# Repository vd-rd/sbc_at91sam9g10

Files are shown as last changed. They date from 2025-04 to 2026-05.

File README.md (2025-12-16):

# Glasnost M9G10 - Open Hardware Linux SBC

An open hardware and software Single Board Computer based on the Microchip AT91SAM9G10, designed for IoT and embedded applications with full SPI/UART/I2C expansion capabilities. This is a learning project exploring Linux board design with mainline kernel support.

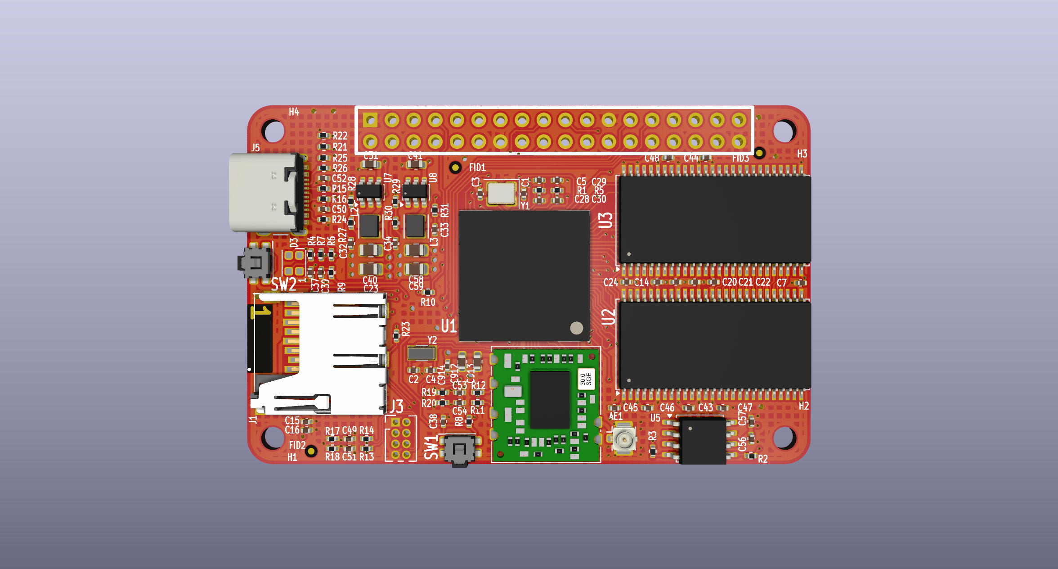
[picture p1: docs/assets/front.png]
board_render


### Features

| Characteristic | Description |
| --- | --- |
| Dimensions | 66mm x 42mm |
| Processor | AT91SAM9G10 - ARM926EJ @ 266MHz |
| Oscillators |  18.432MHz main clock, 32.768kHz RTC |
| RAM | SDRAM 1Gb max (2x 512Mbit modules) |
| Storage | microSD |
| USB | 1 microUSB Host/Client, 2 USB host |
| Ethernet | N/A |
| WiFi/BT | WiFi module onboard |
| Supply | USB, 5V max |
| Interfaces | SPI, UART, I2C, GPIO exposed on headers |
| OS Support | Linux (mainline kernel with custom device tree) |

Common interfaces such as I2C, SPI, UART and GPIO are exposed on the header.

### ⚠️ Boot Note

> **Unlike other Glasnost boards**, this SBC does **not** include NOR Flash for a recovery environment. The AT91SAM9G10's limited peripheral availability means the board relies entirely on microSD card boot. Linux must be booted from the microSD card—there is no fallback recovery distro on internal flash.

### Tools & Design

This project is created using **KiCad 9**

### Documentation & Resources

Complete documentation including schematics, PCB design, and build instructions is available in the [docs](docs/) directory and published at the project website.

For pre-built artifacts:
   - [Fabrication files and releases](https://github.com/vd-rd/sbc_at91sam9g10/releases)

### Status & Licensing

- **Status**: Stable
- **License**: Open Hardware (not officially certified, community design)
- **Open Source**: All hardware designs and software are open source

### References & Inspiration

- [AT91SAM9G10 Datasheet](resources/Atmel-6062-ARM926EJ-S-Microprocessor-SAM9261_Datasheet.pdf)
- [AT91SAM9G10EK Evaluation Kit](https://www.microchip.com/)
- [AT91Bootstrap](https://github.com/linux4sam/at91bootstrap)

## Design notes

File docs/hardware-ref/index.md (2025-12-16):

# Hardware Documentation

This section provides everything you need to understand, replicate, and work with the Glasnost M9G10 board. Whether you're just getting familiar with the design or planning to build your own, the following pages will guide you through each stage.

## 📘 Sections

- [Introduction](introduction.md): An overview of the board’s purpose, key features, and target use cases.
- [Schematics](schematics.md): Detailed circuit diagrams explaining the hardware design.
- [PCB](pcb.md): Information about the board layout, layer stackup, and routing considerations.
- [BOM](bom.md): A full bill of materials with part numbers and sourcing recommendations.
- [Build your own](build-your-own.md): Instructions and files to help you manufacture or assemble your own board.

---

Feel free to explore each section based on your needs, from design deep-dives to practical build guidance.

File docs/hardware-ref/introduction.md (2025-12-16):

# Introduction

The Glasnost M9G10 is an open hardware IoT platform based on the Microchip AT91SAM9G10 SoC. It is designed for projects that require connectivity, reliability, and full control over both software and hardware. The board runs Linux and is intended for embedded applications where flexibility and openness are essential.

## Key Features

- ARM926EJ-S processor @ 266 MHz
- Up to 128 MB low-power SDRAM
- NOR flash for boot and storage
- USB host/device support
- Multiple UARTs, SPI, I²C, GPIO
- Ethernet and other connectivity options
- Fully open hardware design with replicable manufacturing files

## About This Documentation

This section provides the technical resources and guidance needed to understand, replicate, and work with the hardware:
- Schematics and electrical design files
- PCB layout and mechanical notes
- Bill of materials with part numbers
- Assembly guidance and sourcing suggestions

## Intended Audience

This board is intended for:
- Developers building custom IoT hardware
- Researchers designing and testing embedded systems
- Hobbyists and hackers

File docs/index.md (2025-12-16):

---
template: home.html
title: GLASNOST M9G10
---

# Glasnost M9G10

An open hardware and software Single Board Computer based on the Microchip AT91SAM9G10, designed for IoT and embedded applications with full SPI/UART/I2C expansion capabilities.

## Overview

The Glasnost M9G10 is a learning project exploring Linux board design with mainline kernel support. It provides a compact, flexible platform for embedded applications with extensive expansion possibilities through standard interfaces.

### Key Specifications

- **Processor**: AT91SAM9G10 - ARM926EJ @ 266MHz
- **Memory**: Up to 1GB SDRAM (2x 512Mbit modules)
- **Storage**: microSD card
- **Connectivity**: WiFi module onboard, USB (1x microUSB Host/Client, 2x USB host)
- **Interfaces**: SPI, UART, I²C, GPIO exposed on headers
- **Operating System**: Linux with mainline kernel support and custom device tree
- **Size**: 66mm x 42mm

## Important Note

> Unlike other Glasnost boards, this SBC does **not** include NOR Flash for a recovery environment. The AT91SAM9G10's limited peripheral availability means the board relies entirely on microSD card boot.

## Getting Started

Ready to dive in? Check the [Getting Started](getting-started.md) guide to learn how to set up your board and load firmware.

## Documentation

This site contains complete documentation for both hardware and software:

- **[Hardware Documentation](hardware-ref/index.md)**: Schematics, PCB design, BOM, and build instructions
- **[Software Documentation](software-ref/index.md)**: Compilation guides, bootloader details, and OS configuration

## Project Status

- **Status**: Stable
- **License**: Open Hardware (community design)
- **Open Source**: All hardware designs and software are open source

## Resources

- [GitHub Repository](https://github.com/vd-rd/sbc_at91sam9g10)
- [Fabrication Files & Releases](https://github.com/vd-rd/sbc_at91sam9g10/releases)
- [AT91SAM9G10 Datasheet](../resources/Atmel-6062-ARM926EJ-S-Microprocessor-SAM9261_Datasheet.pdf)

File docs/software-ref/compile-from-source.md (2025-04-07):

## Components

This page describes the steps to build an image that can be used with the board, containing a basic linux distribution ready for further hacking.

There are several pieces of software required to put togheter in order to get to an usable shell. Consult the boot documentation for detailed information about the order of execution and relationship between components, but for the purpose of this documentation, the flow looks like this following a board power up:

``` mermaid 
graph LR
A[Embedded ROM] --> B{Find media};
B --> |SD Card| C[AT91Bootstrap];
C --> D[U-Boot];
D --> E[Linux Distro]
B --> |NOR Flash| F[Recovery Distro]
```

The board is equipped with two storage mediums, a NOR Flash soldered on the board and a removable microSD card. the Flash is loaded with a recovery environment suitable for debugging issues. the SD card is loaded with the full flagged distro.

### AT91Bootstrap

This is the second stage loader that is executed by the embedded ROM, after it is found in one of the storage mediums. the loader is executed in the internal SRAM and prepares DRAM, clocks and other peripherals for U-Boot execution. It loads U-Boot and hands over execution. 

For the M9G10 board, a forked AT91Bootstrap is used, where modifications where added to match the hardware configuration. 

In order to compile it first the repo must be cloned and a working arm-none-eabi toolchain must be present.
``` bash
export CROSS_COMPILE=/path/to/arm-none-eabi-
git clone vd-rd/at91bootstrap3
cd AT91Bootstrap
```

The project used menuconfig to select options, akin to Linux kernel and U-Boot. There are two targets that can be selected for the build:
- glasnost_9g10_df_uboot_defconfig
- glasnost_9g10_sd_uboot_defconfig

``` bash
make [target]
make
```

Binary ready to be used will be found in the binary folder.

### U-Boot
This is the 3rd level bootloader, loaded in the last MB of DRAM that further enables board peripherals, loads device tree and overlays if present and starts the kernel. 

### Kernel

### RootFS

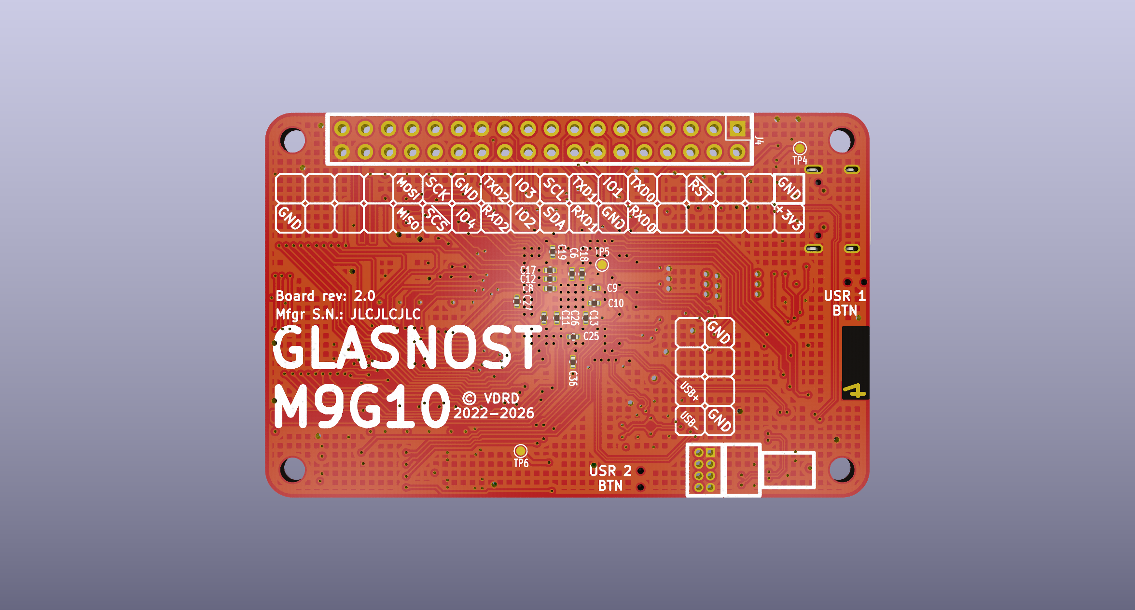
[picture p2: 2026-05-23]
docs/assets/back.png

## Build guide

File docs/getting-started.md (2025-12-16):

## Getting started with your board

To get started you'll need the following:

* a microUSB cable and a power supply
* a microSD card loaded with the necessary firmware

You can connect additional expansion boards that can provide additional functionality, for example:

* a AC-DC board so you can use the board directly from a mains line

## Load firmware on the microSD

To flash an image on the card, you can either go for a prebuilt image, or consult the software section for advanced instructions and configuration.

## First boot
[TBD]

## Next steps

Check the hardware and software section for in-depth overview of specific topics

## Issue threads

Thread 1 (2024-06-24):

Issues with latest fab release

vd-rd, 2024-06-24:
Values are wrong for crystals,
There is no output cap for LDO lines
There is no SPI flash for default strategy boot

Closed 2024-06-25.

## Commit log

2019-05-10 project: structure bringup
    [module_bga.brd, module_bga.sch]
2021-08-13 switch to kicad
    [module_bga.brd, module_bga.sch]
2021-08-13 preliminary board upload
    [cpu.kicad_sch, ethernet.kicad_sch, io.kicad_sch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]
2021-08-20 ready for ddr
    [power.kicad_sch, sbc.kicad_pcb, sbc.kicad_sch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]
2021-08-22 changed dram chips
    [cpu.kicad_sch, power.kicad_sch, sbc.kicad_pcb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]
2021-08-23 added lcd and dram mappings
    [cpu.kicad_sch, io.kicad_sch, lcd.kicad_sch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]
2021-11-25 updated project to be consistent with other sbcs
    [sbc.kicad_pcb]
2021-11-28 add pmic, connect more nets
    [cpu.kicad_sch, io.kicad_sch, lcd.kicad_sch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]
2021-11-30 ensure schematic checklist is passed
    [cpu.kicad_sch, io.kicad_sch, power.kicad_sch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]
2021-12-05 added testpoints
    [cpu.kicad_sch, io.kicad_sch, power.kicad_sch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]
2021-12-07 define gpio signals
    [cpu.kicad_sch, io.kicad_sch, power.kicad_sch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]
2021-12-08 layout done
    [cpu.kicad_sch, io.kicad_sch, sbc.kicad_pcb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]
2021-12-08 added silk text
    [sbc.kicad_pcb]
2021-12-12 added gnd vias
    [sbc.kicad_pcb]
2022-01-02 add board renders
    [sbc.kicad_pcb]
2022-01-16 add layer identification labels
    [sbc.kicad_pcb]
2022-01-19 cosmetic fixes
    [io.kicad_sch, sbc.kicad_pcb, sbc.kicad_sch]
2022-01-19 generated new render
    [sbc.kicad_pcb]
2022-02-02 define pmic version for sam9g10
    [power.kicad_sch, sbc.kicad_sch]
2022-03-24 added fiducials
    [cpu.kicad_sch, power.kicad_sch, sbc.kicad_pcb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]
2024-06-24 bump kicad version
    [cpu.kicad_sch, io.kicad_sch, power.kicad_sch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]
2024-06-25 update render
    [sbc.kicad_pcb]
2024-10-28 board cleanup
    [cpu.kicad_sch, power.kicad_sch, sbc.kicad_pcb]
2025-01-27 reorg and enable docs
    [cpu.kicad_sch, ethernet.kicad_sch, io.kicad_sch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]
2025-02-13 added latest board rev
    [cpu.kicad_sch, power.kicad_sch, sbc.kicad_pcb]
2025-02-13 fixed spi bus error
    [cpu.kicad_sch, sbc.kicad_pcb, sdcard.kicad_sch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]
2025-02-13 fix variables and added system diagram
    [cpu.kicad_sch, io.kicad_sch, power.kicad_sch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]
2025-04-07 Docs (#3)
    * update docs branch (#2)
    * added latest board rev
    * fixed spi bus error
    * Update FUNDING.yml
    * fix variables and added system diagram
    * Update compile-from-source.md
    * Update compile-from-source.md
    * added latest changes
    [cpu.kicad_sch, io.kicad_sch, power.kicad_sch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]
2025-04-07 fix board render
2025-12-16 rework for v2 (#4)
    [io.kicad_sch, power.kicad_sch, sbc.kicad_sch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]
2026-02-01 finished routing
    [cpu.kicad_sch, power.kicad_sch, sbc.kicad_sch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]
2026-02-02 board housekeeping
    [io.kicad_sch, sbc.kicad_sch, sdcard.kicad_sch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]
2026-05-23 prepare board for rev2 order
    [cpu.kicad_sch, io.kicad_sch, power.kicad_sch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]
2026-05-23 update board renders for rev2
2026-07-14 backport project changes
    [cpu.kicad_sch, io.kicad_sch, power.kicad_sch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]
